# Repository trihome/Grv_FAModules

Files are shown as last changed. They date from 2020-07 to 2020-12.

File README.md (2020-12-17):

# FA Extension boards for Grove System

## 1.Introduction

This repository has an interface board for connecting equipment used in the factory to Seeed Studio's "Grove System".

<http://wiki.seeedstudio.com/Grove_System/>

These modules are used to make the equipment used in the factory (switches, sensors, relays, etc.) Allows you to connect to the GROVE system.

These boards support digital (GPIO), analog, and I2C connection types.

Refer to the READEME file in each directory for more information.

**Note**

Please import this library before using this repository.
<https://github.com/trihome/KiCad_MyLibrary>

**How to make**

[Manual (Japanese only)](https://github.com/trihome/RasPi_PiFA/blob/master/doc/README_pcb.jp.md)

## 2.Line up

|Module|Connection Type |function |
|:---|:---|:---|
|[IOExpander](./IOExpander16ch/) |I2C |Isolated input/output via I2C |
|[DigitalOutput](./DigitalOutput4ch)  |GPIO |Isolated output  |
|[DigitalInput](./DigitalInput4ch) |GPIO |Isolated input |
| | |(We will increase the lineup in the future...) |
<!--|CurrentSensor  |Analog  |Current measurement using CT  |
|SigTowSensor   |Analog  |Detect tower light status   |
|SimpleUPS      |GPIO    |Manage the power supply to RaspberryPi   |-->

## 3.How to connect to microcomputer board

If your board does not have a Grove connector, obtain a **Grove Expansion Board** to connect your Grove module.

- <http://wiki.seeedstudio.com/Platform/>

### (1)Arduino

- <http://wiki.seeedstudio.com/Base_Shield_V2/>

### (2)Raspberry Pi

- <http://wiki.seeedstudio.com/Grove_Base_Hat_for_Raspberry_Pi/>
- <http://wiki.seeedstudio.com/Grove_Base_Hat_for_Raspberry_Pi_Zero/>

### (3)micro:bit

- <https://www.seeedstudio.com/Grove-Shield-for-micro-bit-v2-0.html>

## 4.License

This is under [CC-BY-SA](https://creativecommons.org/licenses/by-sa/4.0/).

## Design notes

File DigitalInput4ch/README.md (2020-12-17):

# Digital Input 4ch

Digital Input for GROVE Digital.
Isolated inputs.

[Schematic](./img/DigitalInput4ch.pdf)

**Notes**

Please import this library before using this repository.
https://github.com/trihome/KiCad_MyLibrary

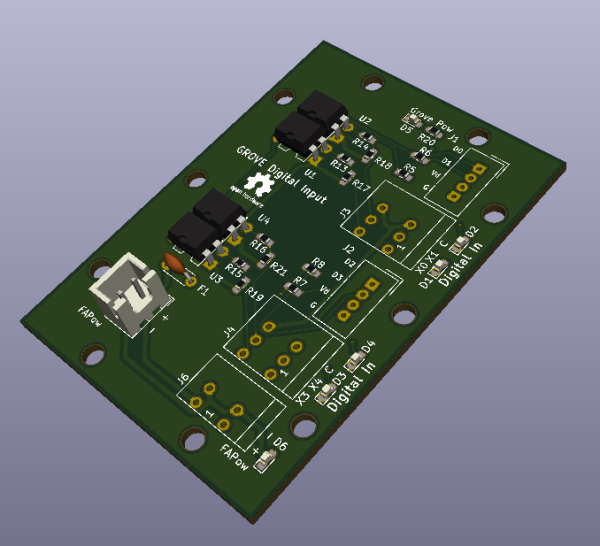
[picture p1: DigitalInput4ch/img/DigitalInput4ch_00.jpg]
di00 3D

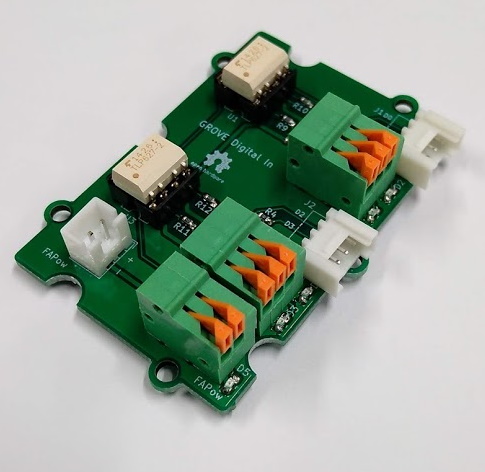
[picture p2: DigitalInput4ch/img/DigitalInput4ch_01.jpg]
di01 Usage


## 1.Spec

- 4 isolated inputs.
- [GROVE Digital](https://wiki.seeedstudio.com/Grove_System/#digital) Connector x 2 (2ch x 2 = 4ch)
- Supply 24V power to J5 or J6.
- J3,6 are Input for FA(24V)
  - Recommended Terminal block: [2pin](https://akizukidenshi.com/catalog/g/gP-06307/), [3pin](https://akizukidenshi.com/catalog/g/gP-06308/)
- Selectable Sink(NPN) / Source(PNP) : JP1, JP2
- U1,2,3,4: Photocoupler, you have to choose...

|JP1, JP2|Photocoupler (ex)|
|:--|:--|
|N : Sink(NPN)|[FOD814A300W](https://akizukidenshi.com/catalog/g/gI-06483/), [TLP627](https://akizukidenshi.com/catalog/g/gI-07691/)|
|P : Source(PNP)|[FOD814A300W](https://akizukidenshi.com/catalog/g/gI-06483/)|

## 2.Example of use

<!--
### (1)Terminal block

- Button
  - [IDEC](http://jp.idec.com/ja/p/c10/)
  - [OMRON](https://www.fa.omron.co.jp/products/category/switches/push-buttons_indicator-lamps/)
- Lamp
  - [NIKKEI MFG](http://www.nikkei-mfg.co.jp/product/industry/index.htm)
-->

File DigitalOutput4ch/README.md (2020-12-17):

# Digital Output 4ch

Digital Output for GROVE Digital.
Isolated outputs.

[Schematic](./img/DigitalOutput4ch.pdf)

**Notes**

Please import this library before using this repository.
https://github.com/trihome/KiCad_MyLibrary

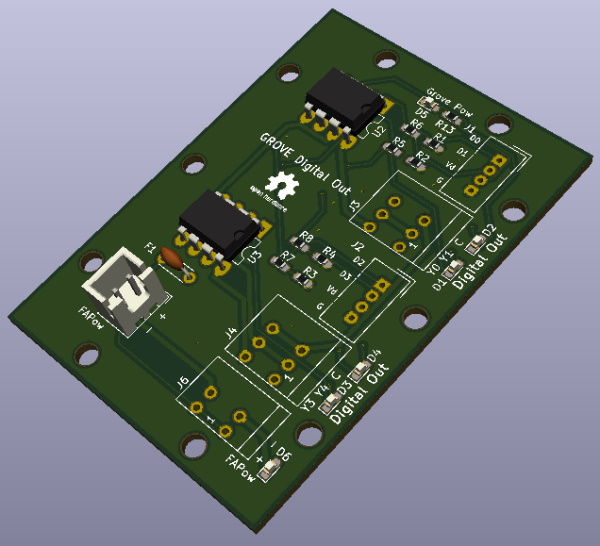
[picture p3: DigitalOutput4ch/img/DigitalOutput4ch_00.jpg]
do00 3D

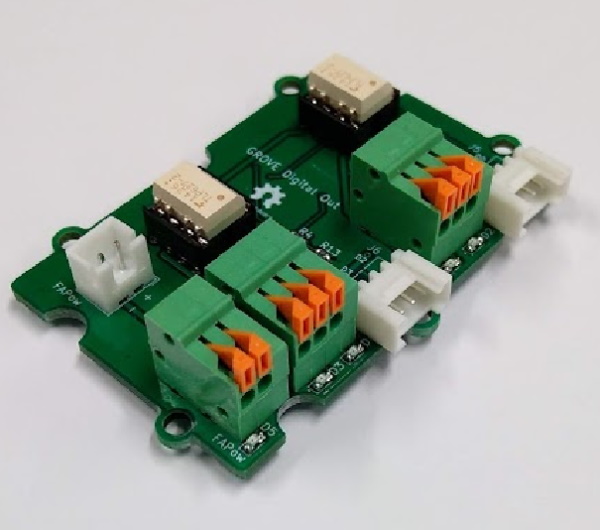
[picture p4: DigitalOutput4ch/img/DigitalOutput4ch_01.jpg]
do01 Usage


## 1.Spec

- 4 isolated outputs.
- [GROVE Digital](https://wiki.seeedstudio.com/Grove_System/#digital) Connector x 2 (2ch x 2 = 4ch)
- Supply 24V power to J5 or J6.
- J3,6 are Input for FA(24V)
  - Recommended Terminal block: [2pin](https://akizukidenshi.com/catalog/g/gP-06307/), [3pin](https://akizukidenshi.com/catalog/g/gP-06308/)
- Selectable Sink(NPN) / Source(PNP) : JP1, JP2
- U1,2,3,4: Photocoupler, you have to choose...

|JP1, JP2|Photocoupler (ex)|
|:--|:--|
|N : Sink(NPN)|[TLP222A](https://akizukidenshi.com/catalog/g/gI-07672/), [TLP627](https://akizukidenshi.com/catalog/g/gI-07691/)|
|P : Source(PNP)|[TLP222A](https://akizukidenshi.com/catalog/g/gI-07672/)|

## 2.Example of use

<!--
### (1)Terminal block

- Button
  - [IDEC](http://jp.idec.com/ja/p/c10/)
  - [OMRON](https://www.fa.omron.co.jp/products/category/switches/push-buttons_indicator-lamps/)
- Lamp
  - [NIKKEI MFG](http://www.nikkei-mfg.co.jp/product/industry/index.htm)
-->

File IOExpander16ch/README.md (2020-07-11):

# IO Expander 16ch

IO Expander for GROVE I2C.
Isolated inputs and outputs.

[Schematic](./img/IOExpander16ch.pdf)

**Notes**

Please import this library before using this repository.
https://github.com/trihome/KiCad_MyLibrary

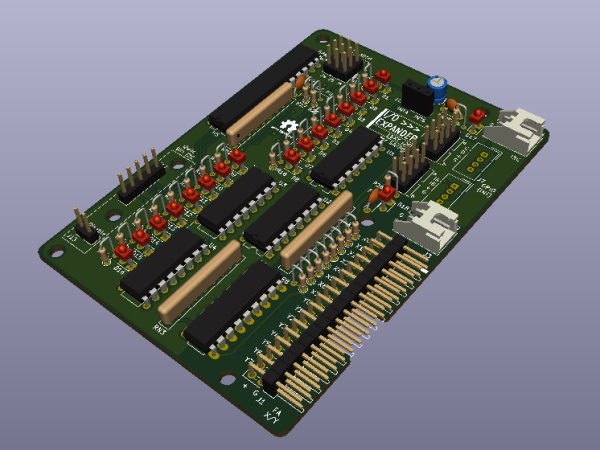
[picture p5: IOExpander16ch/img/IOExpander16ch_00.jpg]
ioexp1600 3D

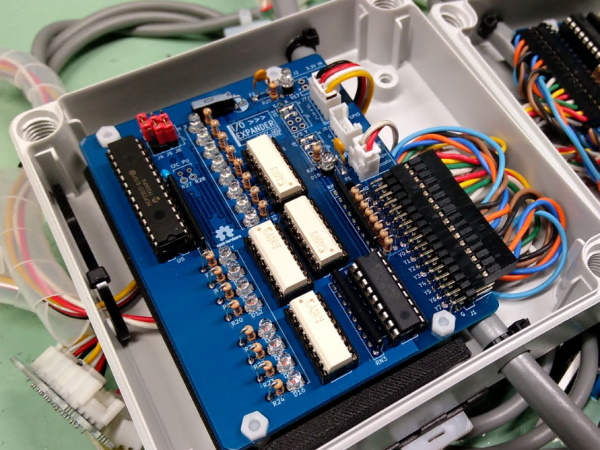
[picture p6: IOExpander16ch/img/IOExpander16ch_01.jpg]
ioexp1601 Usage


## 1.Spec

- 8 isolated inputs and 8 isolated outputs.
- I/O Expander : MCP23017
  - Select I2C address, J4,J5,J6.
  - I2C signal input to J7 (GROVE I2C).
  - INT A, B Pins are output to J8 (GROVE Digital).
- Supply 24V power to J3.
- J1 is Input / Output for FA(24V)
  - Recommended [Terminal block](https://www.togi.co.jp/product/interface/1072/) and [Cables](https://www.togi.co.jp/product/harness-cable/2661/) or QI(2550)connectors.
- Selectable Sink(NPN) / Source(PNP) : J9(Input), J10(Output)
  - IC1: Transistor array, you have to choose.
    - J10 = [Sink(NPN)](http://akizukidenshi.com/catalog/g/gI-10669/)
    - J10 = [Source(PNP)](http://akizukidenshi.com/catalog/g/gI-10957/)
- If you want to communicate with a distant location, add this board.
- [SparkFun Differential I2C Breakout - PCA9615](https://www.switch-science.com/catalog/3907/)

## 2.Example of use

### (1)Terminal block

- Terminal block (34 pin)
  - [Screw connection](https://www.togi.co.jp/product/interface/958/)
  - [Push-in connection(Ferrules)](https://www.togi.co.jp/product/interface/1086)
- [Cables](https://www.togi.co.jp/series/harness-cable/284/)
- Button
  - [IDEC](http://jp.idec.com/ja/p/c10/)
  - [OMRON](https://www.fa.omron.co.jp/products/category/switches/push-buttons_indicator-lamps/)
- Lamp
  - [NIKKEI MFG](http://www.nikkei-mfg.co.jp/product/industry/index.htm)

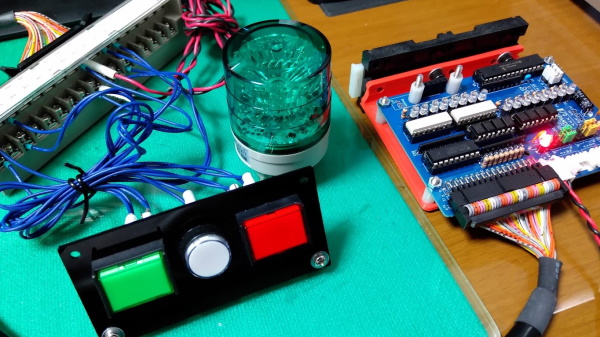
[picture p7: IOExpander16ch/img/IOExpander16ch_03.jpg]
ioexp1603 Usage

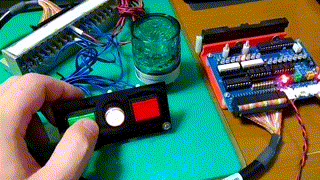
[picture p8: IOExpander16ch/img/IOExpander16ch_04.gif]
ioexp1604 Usage


### (2)Communicate with a device in a remote location

- [SparkFun Differential I2C Breakout - PCA9615](https://www.switch-science.com/catalog/3907/)
  - Connect to J12.
- Ethernet Cables (MAX 30 m)

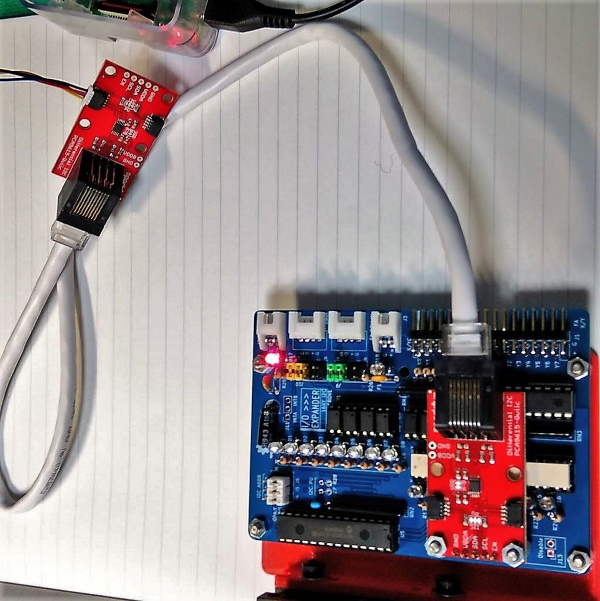
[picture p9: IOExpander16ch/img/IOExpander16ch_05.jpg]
ioexp1605 Usage

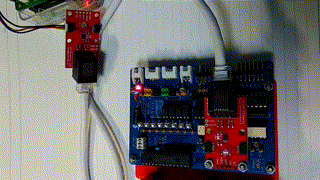
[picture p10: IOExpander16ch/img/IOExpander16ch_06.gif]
ioexp1606 Usage


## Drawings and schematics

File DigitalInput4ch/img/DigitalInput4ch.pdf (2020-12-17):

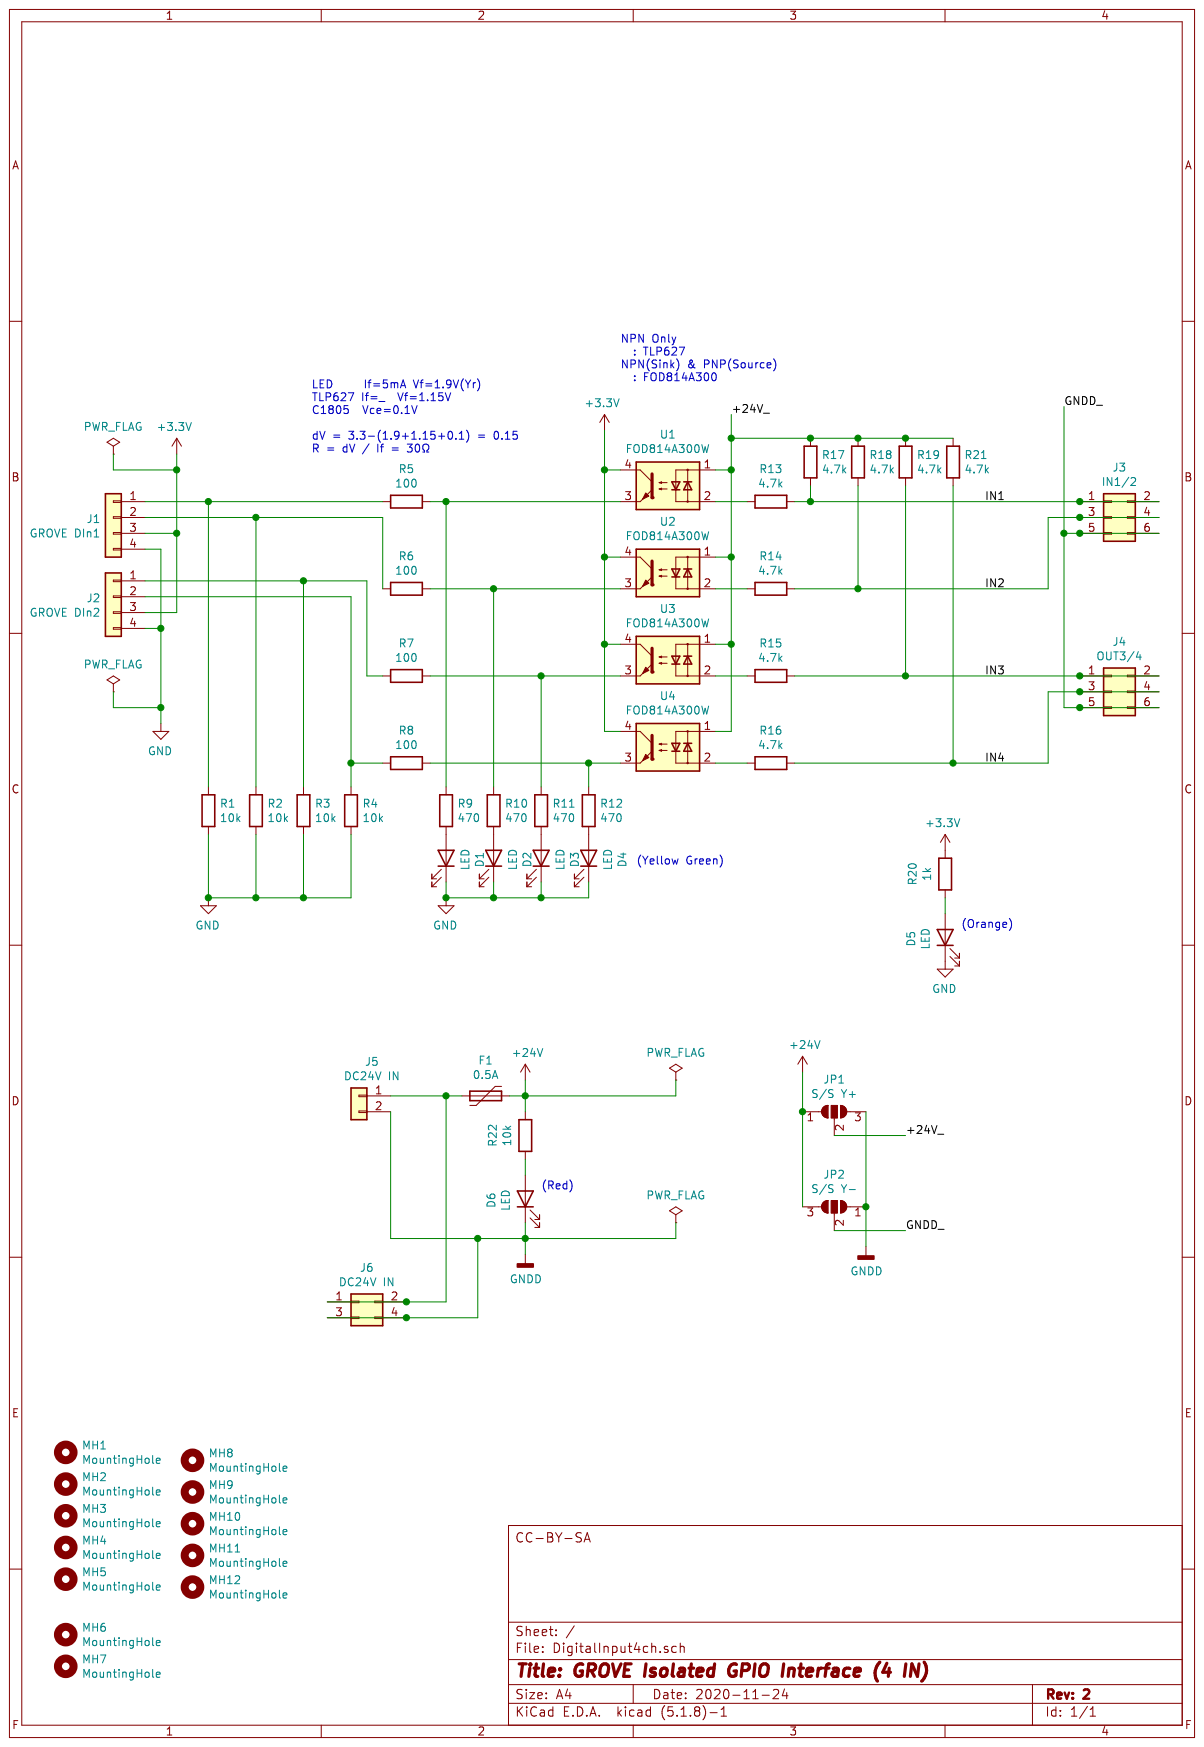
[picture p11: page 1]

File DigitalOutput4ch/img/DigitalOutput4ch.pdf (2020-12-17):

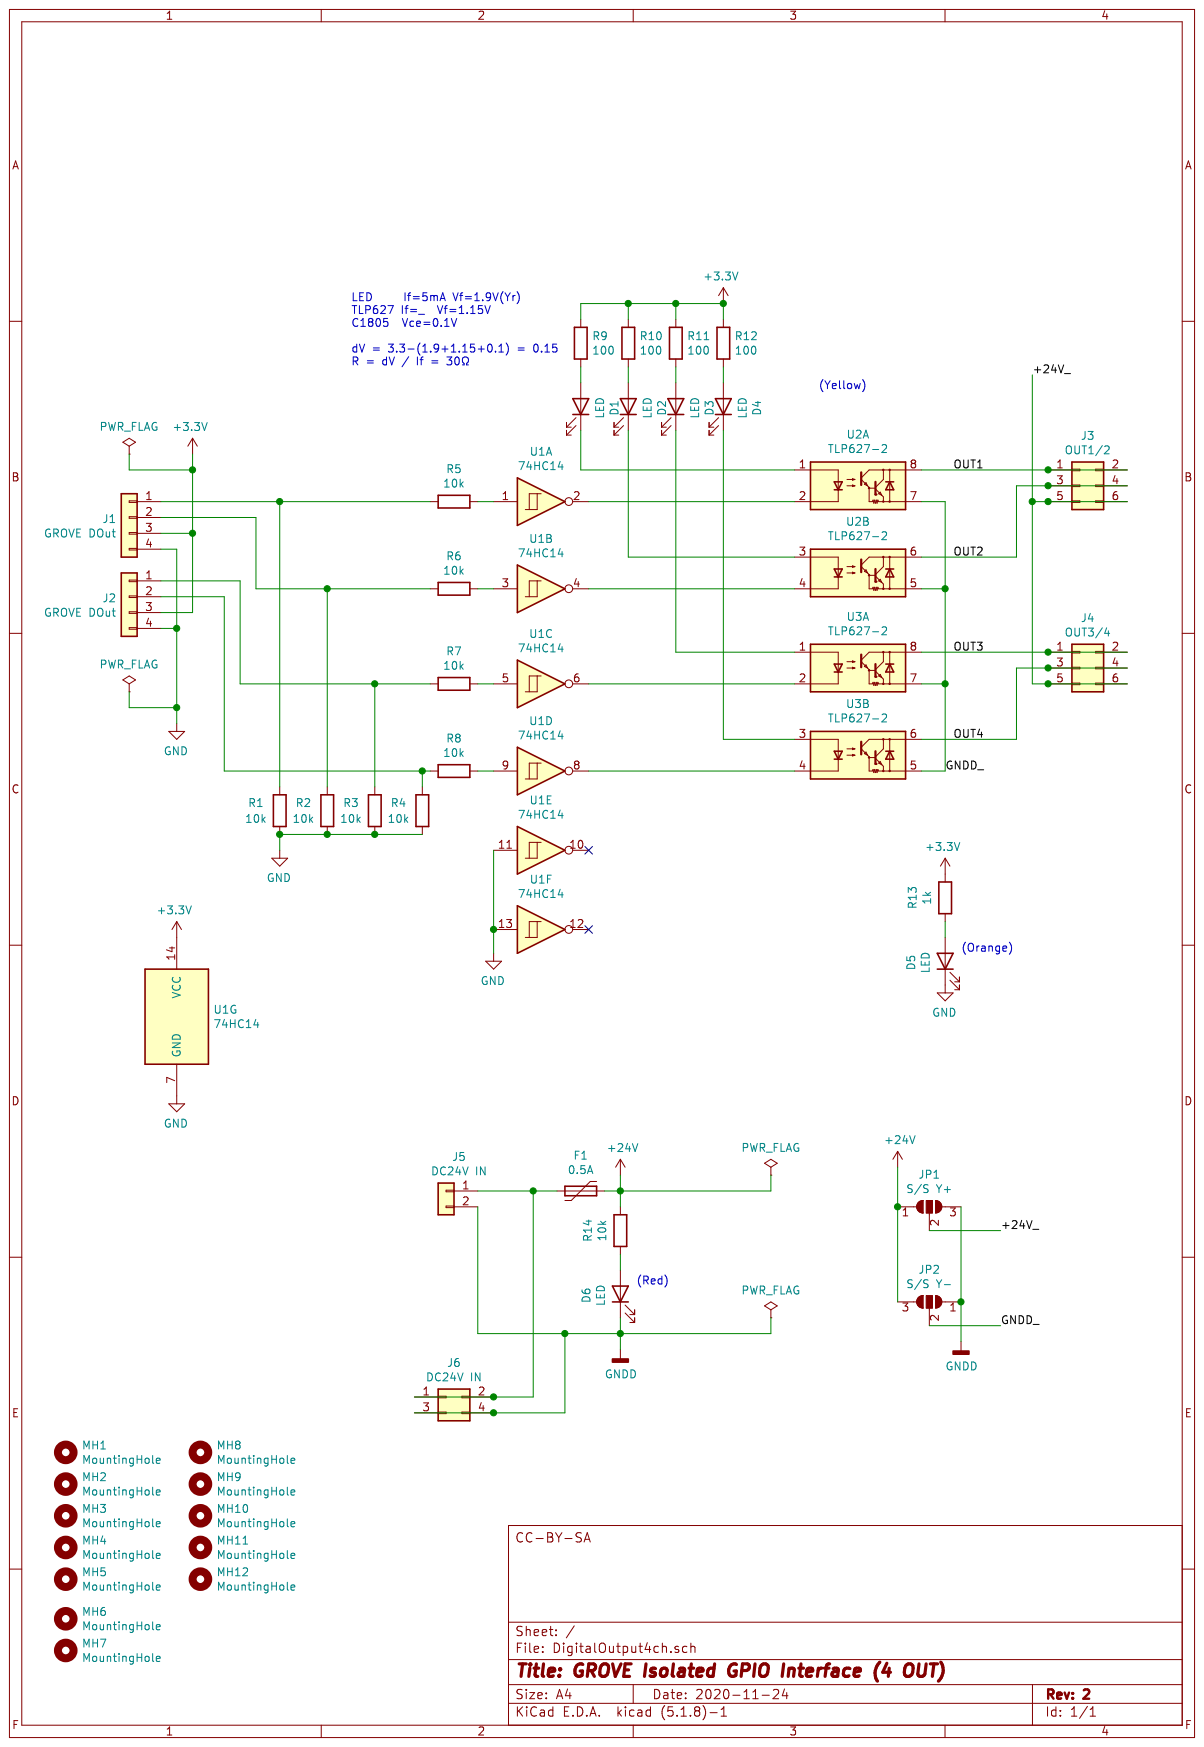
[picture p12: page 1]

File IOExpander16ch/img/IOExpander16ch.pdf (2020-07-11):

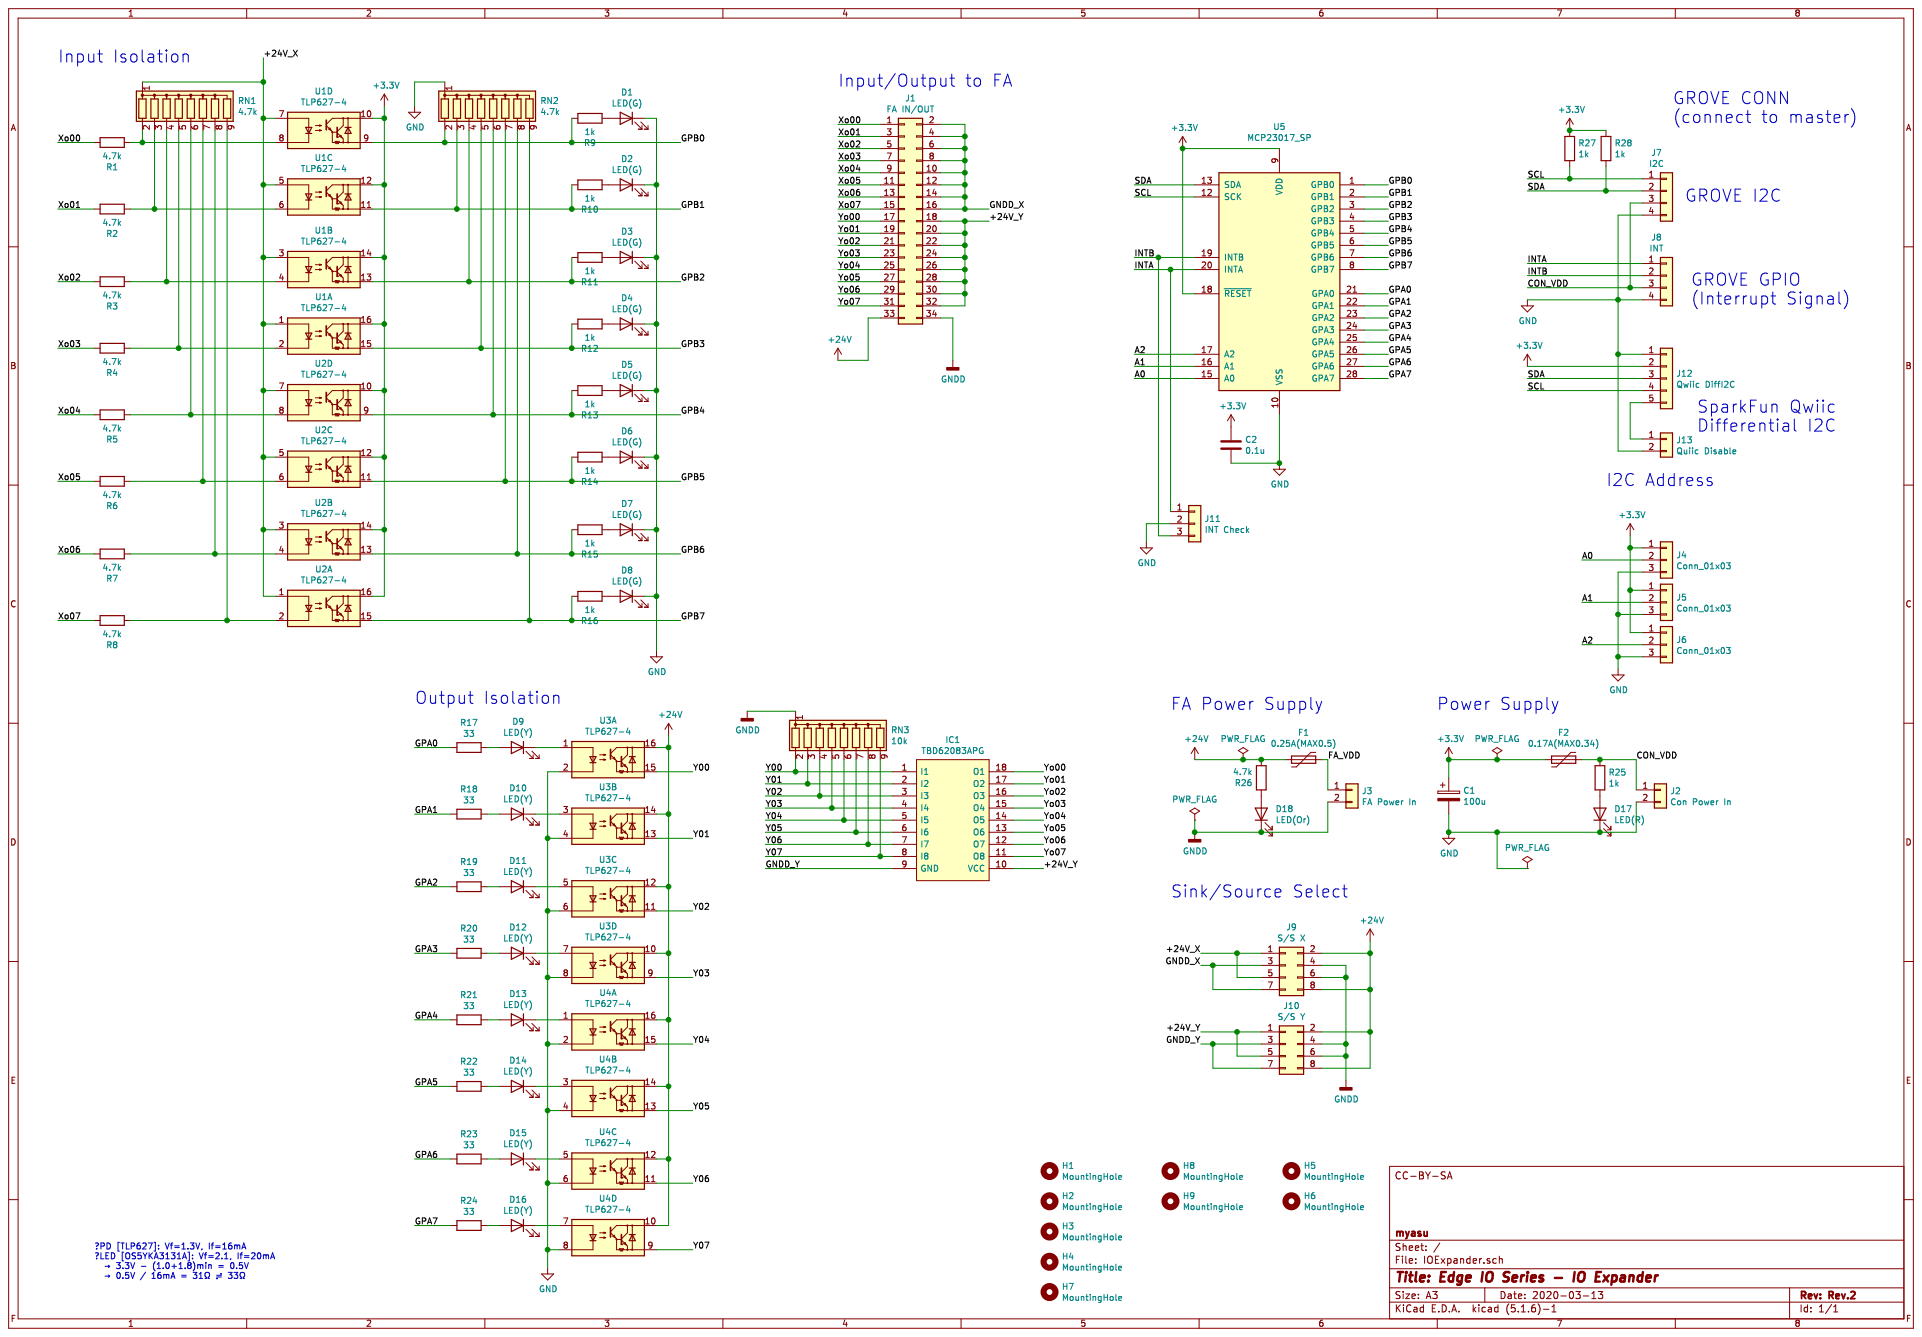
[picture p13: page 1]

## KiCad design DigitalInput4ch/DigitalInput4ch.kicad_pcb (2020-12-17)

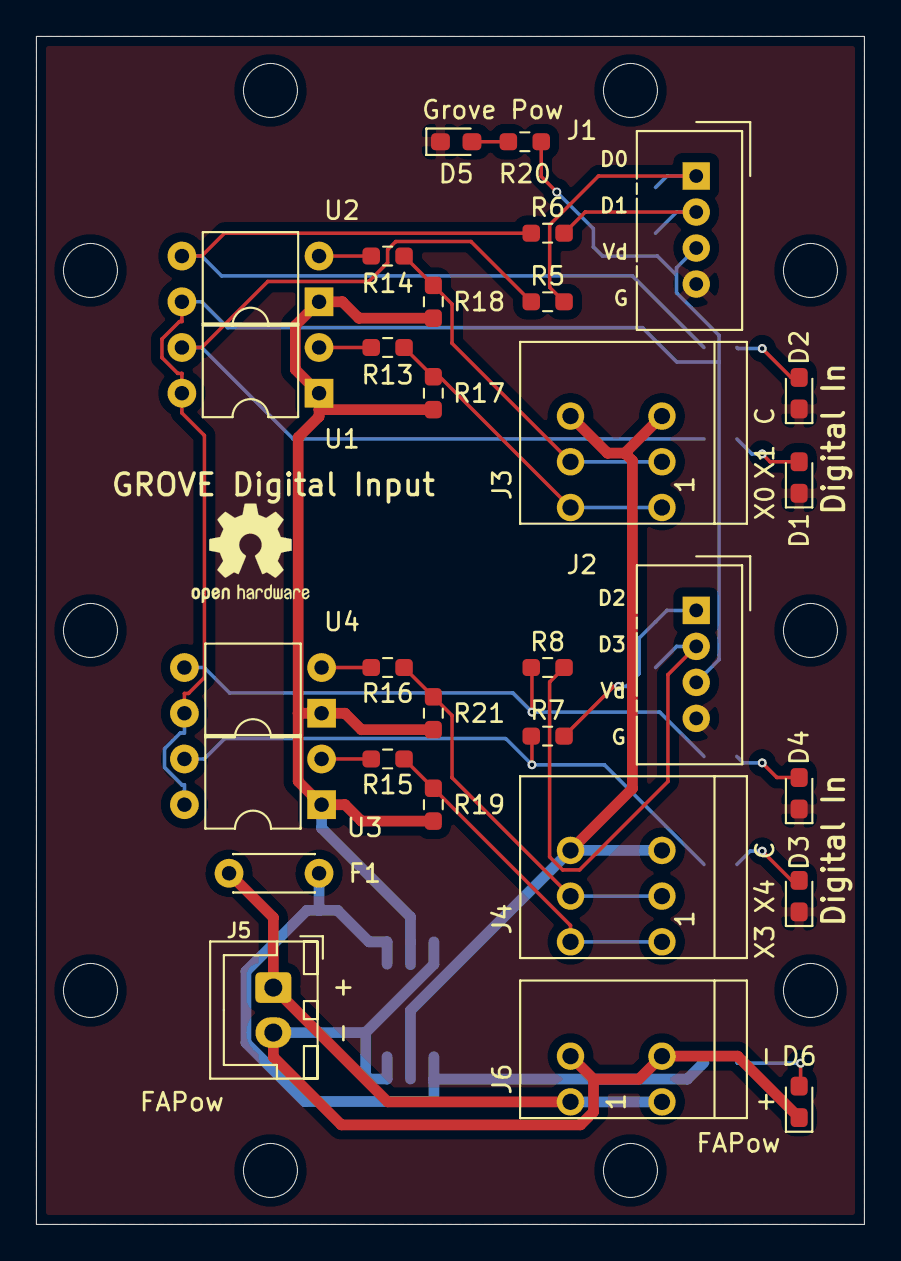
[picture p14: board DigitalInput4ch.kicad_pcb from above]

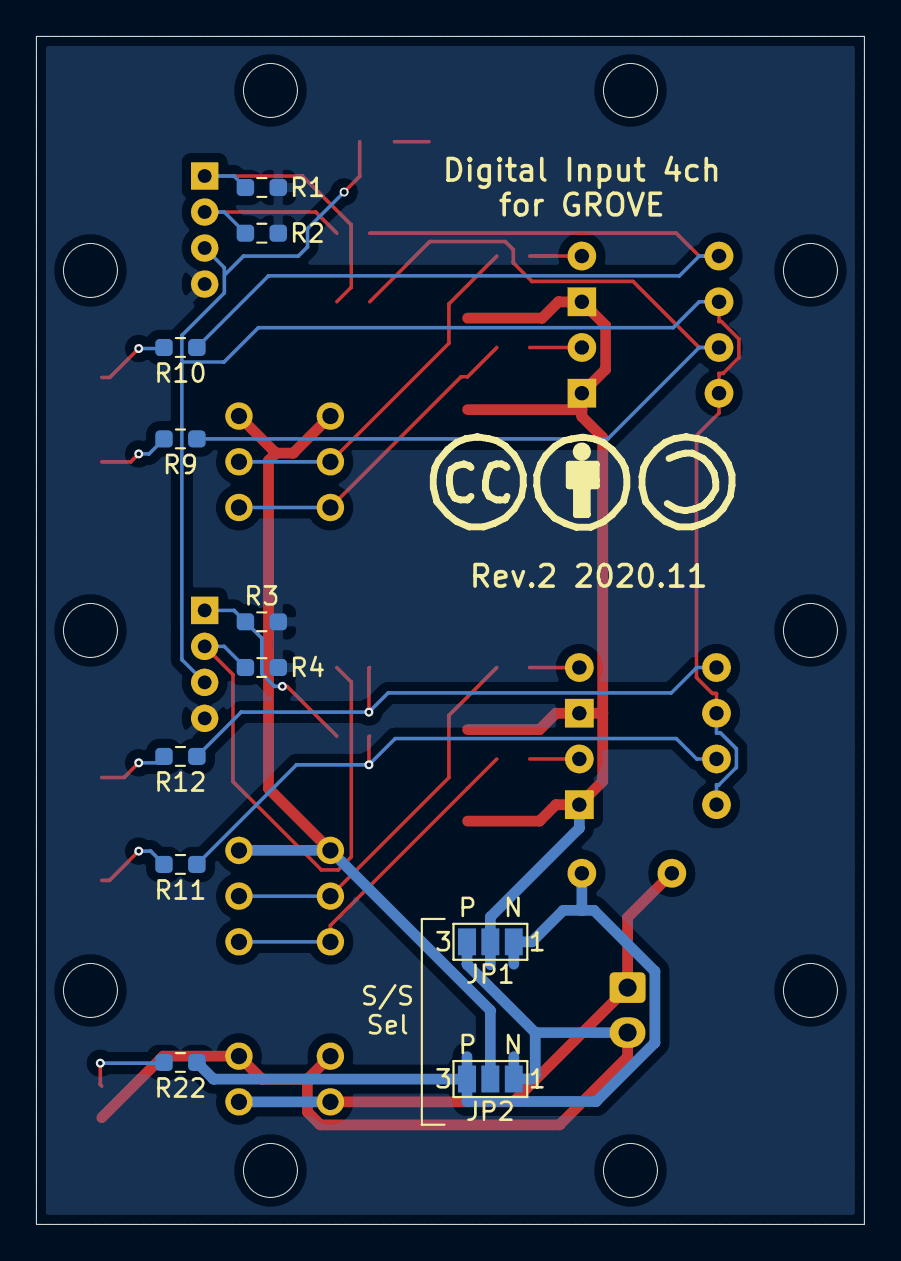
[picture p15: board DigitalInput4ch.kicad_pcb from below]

Board: 2 copper layers, 46.0 x 66.0 mm, 53 parts (11 on the bottom side), 29 nets.

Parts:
D1, D2, D3, D4, D5, D6: LED; LED_0603_1608Metric_Pad1.05x0.95mm_HandSolder
F1: 0.5A; C_Disc_D4.3mm_W1.9mm_P5.00mm
J1: GROVE DIn1; NS-Tech_Grove_1x04_P2mm_Vertical
J2: GROVE DIn2; NS-Tech_Grove_1x04_P2mm_Vertical
J3: IN1/2; Terminal_TB401a-1-3-E
J4: OUT3/4; Terminal_TB401a-1-3-E
J5: DC24V IN; JST_XH_B2B-XH-A_1x02_P2.50mm_Vertical
J6: DC24V IN; Terminal_TB401a-1-2-E
JP1: S/S Y+; SolderJumper-3_P1.3mm_Open_Pad1.0x1.5mm_NumberLabels
JP2: S/S Y-; SolderJumper-3_P1.3mm_Open_Pad1.0x1.5mm_NumberLabels
MH1, MH2, MH3, MH4, MH5, MH8, MH9, MH10, MH11, MH12: MountingHole; MountingHole_3mm
MH6: MountingHole; OSHW-Logo2_7.3x6mm_SilkScreen
MH7: MountingHole; CC-BY-SA
R1, R2, R3, R4, R22: 10k; R_0603_1608Metric_Pad0.98x0.95mm_HandSolder
R5, R6, R7, R8: 100; R_0603_1608Metric_Pad0.98x0.95mm_HandSolder
R9, R10, R11, R12: 470; R_0603_1608Metric_Pad0.98x0.95mm_HandSolder
R13, R14, R15, R16, R17, R18, R19, R21: 4.7k; R_0603_1608Metric_Pad0.98x0.95mm_HandSolder
R20: 1k; R_0603_1608Metric_Pad0.98x0.95mm_HandSolder
U1, U2, U3, U4: FOD814A300W; DIP-4_W7.62mm

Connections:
+3V3: J1.3, J2.3, R20.1, U1.4, U2.4, U3.4, U4.4
+24V: F1.1, JP1.1, JP2.3, R22.1
/+24V_: JP1.2, R17.1, R18.1, R19.1, R21.1, U1.1, U2.1, U3.1, U4.1
/GNDD_: J3.5, J3.6, J4.5, J4.6, JP2.2
/IN1: J3.1, J3.2, R13.1, R17.2
/IN2: J3.3, J3.4, R14.1, R18.2
/IN3: J4.1, J4.2, R15.1, R19.2
/IN4: J4.3, J4.4, R16.1, R21.2
GND: D1.1, D2.1, D3.1, D4.1, D5.1, J1.4, J2.4, R1.2, R2.2, R3.2, R4.2
GNDD: D6.1, J5.2, J6.3, J6.4, JP1.3, JP2.1
unnamed: D1.2, R9.2
unnamed: D2.2, R10.2
unnamed: D3.2, R11.2
unnamed: D4.2, R12.2
unnamed: D5.2, R20.2
unnamed: D6.2, R22.2
unnamed: F1.2, J5.1, J6.1, J6.2
unnamed: J1.1, R1.1, R5.2
unnamed: J1.2, R2.1, R6.2
unnamed: J2.1, R3.1, R7.2
unnamed: J2.2, R4.1, R8.2
unnamed: R5.1, R9.1, U1.3
unnamed: R6.1, R10.1, U2.3
unnamed: R7.1, R11.1, U3.3
unnamed: R8.1, R12.1, U4.3
unnamed: R13.2, U1.2
unnamed: R14.2, U2.2
unnamed: R15.2, U3.2
unnamed: R16.2, U4.2

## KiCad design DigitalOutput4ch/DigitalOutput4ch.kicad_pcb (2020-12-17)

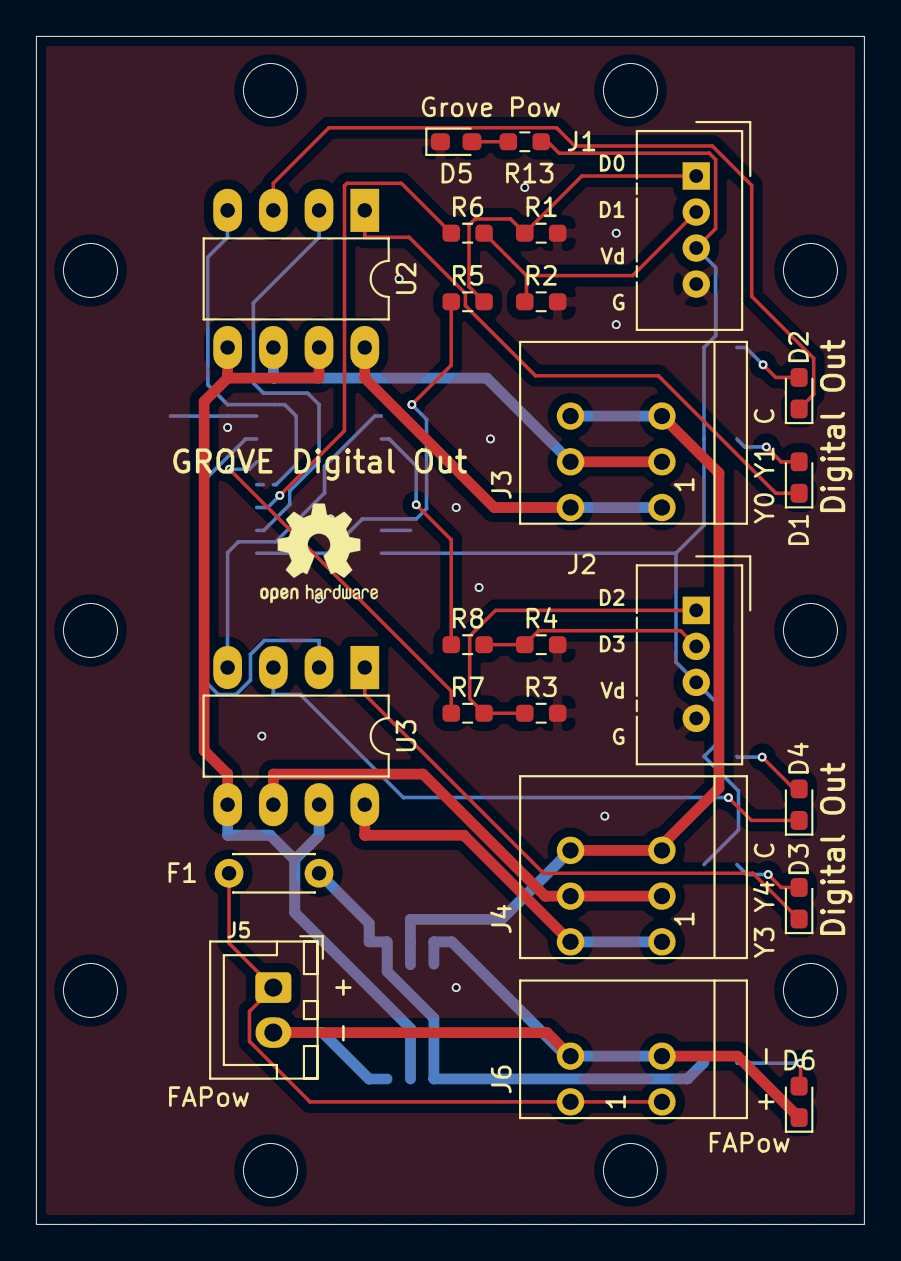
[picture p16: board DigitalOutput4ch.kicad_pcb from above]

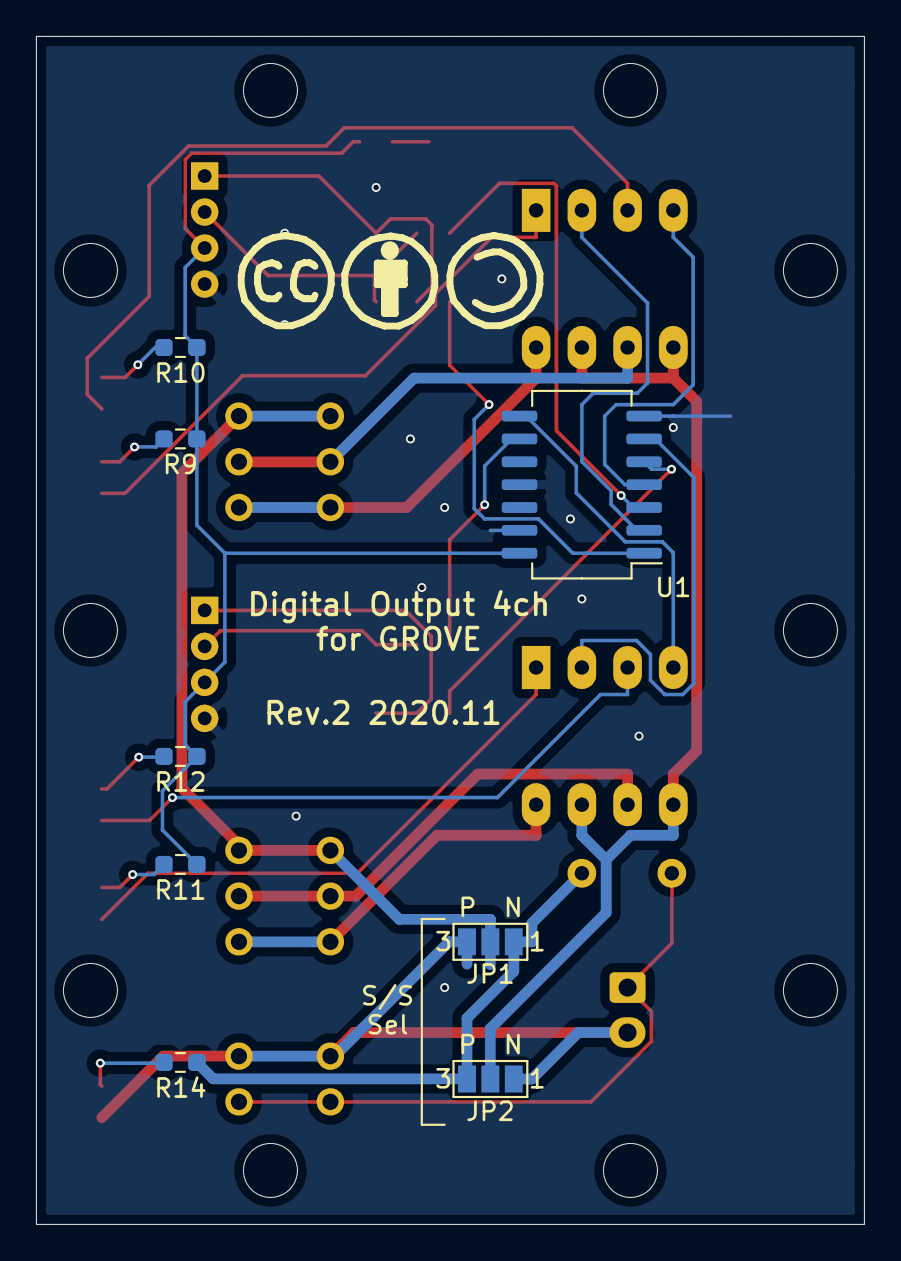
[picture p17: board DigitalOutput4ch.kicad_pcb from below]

Board: 2 copper layers, 46.0 x 66.0 mm, 44 parts (8 on the bottom side), 33 nets.

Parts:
D1, D2, D3, D4, D5, D6: LED; LED_0603_1608Metric_Pad1.05x0.95mm_HandSolder
F1: 0.5A; C_Disc_D4.3mm_W1.9mm_P5.00mm
J1, J2: GROVE DOut; NS-Tech_Grove_1x04_P2mm_Vertical
J3: OUT1/2; Terminal_TB401a-1-3-E
J4: OUT3/4; Terminal_TB401a-1-3-E
J5: DC24V IN; JST_XH_B2B-XH-A_1x02_P2.50mm_Vertical
J6: DC24V IN; Terminal_TB401a-1-2-E
JP1: S/S Y+; SolderJumper-3_P1.3mm_Open_Pad1.0x1.5mm_NumberLabels
JP2: S/S Y-; SolderJumper-3_P1.3mm_Open_Pad1.0x1.5mm_NumberLabels
MH1, MH2, MH3, MH4, MH5, MH8, MH9, MH10, MH11, MH12: MountingHole; MountingHole_3mm
MH6: MountingHole; OSHW-Logo2_7.3x6mm_SilkScreen
MH7: MountingHole; CC-BY-SA
R1, R2, R3, R4, R5, R6, R7, R8, R14: 10k; R_0603_1608Metric_Pad0.98x0.95mm_HandSolder
R9, R10, R11, R12: 100; R_0603_1608Metric_Pad0.98x0.95mm_HandSolder
R13: 1k; R_0603_1608Metric_Pad0.98x0.95mm_HandSolder
U1: 74HC14; SO-14_5.3x10.2mm_P1.27mm
U2, U3: TLP627-2; DIP-8_W7.62mm_LongPads

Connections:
+3V3: J1.3, J2.3, R9.1, R10.1, R11.1, R12.1, R13.1, U1.14
+24V: F1.1, JP1.1, JP2.3, R14.1
/+24V_: J3.5, J3.6, J4.5, J4.6, JP1.2
/GNDD_: JP2.2, U2.5, U2.7, U3.5, U3.7
/OUT1: J3.1, J3.2, U2.8
/OUT2: J3.3, J3.4, U2.6
/OUT3: J4.1, J4.2, U3.8
/OUT4: J4.3, J4.4, U3.6
GND: D5.1, J1.4, J2.4, R1.2, R2.2, R3.2, R4.2, U1.7, U1.11, U1.13
GNDD: D6.1, J5.2, J6.3, J6.4, JP1.3, JP2.1
unnamed: D1.1, U2.1
unnamed: D1.2, R9.2
unnamed: D2.1, U2.3
unnamed: D2.2, R10.2
unnamed: D3.1, U3.1
unnamed: D3.2, R11.2
unnamed: D4.1, U3.3
unnamed: D4.2, R12.2
unnamed: D5.2, R13.2
unnamed: D6.2, R14.2
unnamed: F1.2, J5.1, J6.1, J6.2
unnamed: J1.1, R1.1, R5.2
unnamed: J1.2, R2.1, R6.2
unnamed: J2.1, R3.1, R7.2
unnamed: J2.2, R4.1, R8.2
unnamed: R5.1, U1.1
unnamed: R6.1, U1.3
unnamed: R7.1, U1.5
unnamed: R8.1, U1.9
unnamed: U1.2, U2.2
unnamed: U1.4, U2.4
unnamed: U1.6, U3.2
unnamed: U1.8, U3.4

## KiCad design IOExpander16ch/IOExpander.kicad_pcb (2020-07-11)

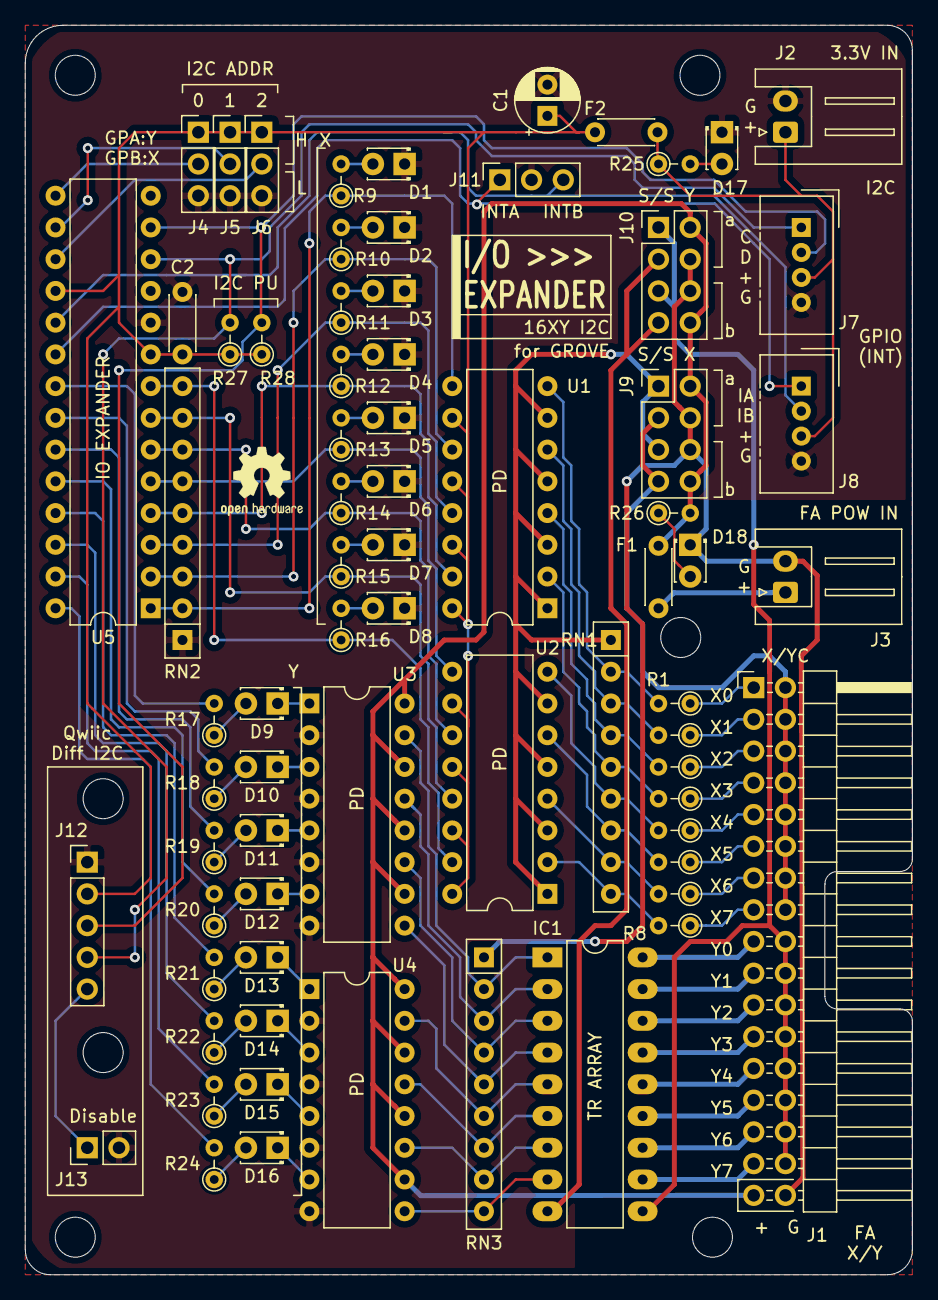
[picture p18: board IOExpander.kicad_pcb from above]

Board: 2 copper layers, 71.0 x 100.0 mm, 81 parts (0 on the bottom side), 92 nets.

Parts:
C1: 100u; CP_Radial_D5.0mm_P2.50mm
C2: 0.1u; C_Disc_D4.3mm_W1.9mm_P5.00mm
D1, D2, D3, D4, D5, D6, D7, D8: LED(G); LED_D1.8mm_W3.3mm_H2.4mm
D9, D10, D11, D12, D13, D14, D15, D16: LED(Y); LED_D1.8mm_W3.3mm_H2.4mm
D17: LED(R); LED_D1.8mm_W3.3mm_H2.4mm
D18: LED(Or); LED_D1.8mm_W3.3mm_H2.4mm
F1: 0.25A(MAX0.5); C_Disc_D4.3mm_W1.9mm_P5.00mm
F2: 0.17A(MAX0.34); C_Disc_D4.3mm_W1.9mm_P5.00mm
H1, H2, H3, H4, H7, H8, H9: MountingHole; MountingHole_3.2mm_M3
H5: MountingHole; OSHW-Logo2_7.3x6mm_SilkScreen
H6: MountingHole; CC-BY-SA
IC1: TBD62083APG; DIP-18_W7.62mm_LongPads
J1: FA IN/OUT; PinHeader_2x17_P2.54mm_Horizontal
J2: Con Power In; JST_XH_S2B-XH-A_1x02_P2.50mm_Horizontal
J3: FA Power In; JST_XH_S2B-XH-A_1x02_P2.50mm_Horizontal
J4, J5, J6: Conn_01x03; PinHeader_1x03_P2.54mm_Vertical
J7: I2C; NS-Tech_Grove_1x04_P2mm_Vertical
J8: INT; NS-Tech_Grove_1x04_P2mm_Vertical
J9: S/S X; PinHeader_2x04_P2.54mm_Vertical
J10: S/S Y; PinHeader_2x04_P2.54mm_Vertical
J11: INT Check; PinSocket_1x03_P2.54mm_Vertical
J12: Qwiic DiffI2C; PinHeader_1x05_P2.54mm_Vertical
J13: Quiic Disable; PinHeader_1x02_P2.54mm_Vertical
R1, R2, R3, R4, R5, R6, R7, R8, R26: 4.7k; R_Axial_DIN0204_L3.6mm_D1.6mm_P2.54mm_Vertical
R9, R10, R11, R12, R13, R14, R15, R16, R25, R27, R28: 1k; R_Axial_DIN0204_L3.6mm_D1.6mm_P2.54mm_Vertical
R17, R18, R19, R20, R21, R22, R23, R24: 33; R_Axial_DIN0204_L3.6mm_D1.6mm_P2.54mm_Vertical
RN1, RN2: 4.7k; R_Array_SIP9
RN3: 10k; R_Array_SIP9
U1, U2, U3, U4: TLP627-4; DIP-16_W7.62mm
U5: MCP23017_SP; DIP-28_W7.62mm

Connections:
+3V3: C1.1, C2.1, F2.2, J4.1, J5.1, J6.1, J12.2, R27.1, R28.1, U1.10, U1.12, U1.14, U1.16, U2.10, U2.12, U2.14, U2.16, U5.9, U5.18
+24V: F1.2, J1.33, J9.2, J9.8, J10.2, J10.8, R26.2, U3.10, U3.12, U3.14, U3.16, U4.10, U4.12, U4.14, U4.16
/+24V_X: J9.1, J9.5, RN1.1, U1.1, U1.3, U1.5, U1.7, U2.1, U2.3, U2.5, U2.7
/+24V_Y: IC1.10, J1.18, J1.20, J1.22, J1.24, J1.26, J1.28, J1.30, J1.32, J10.1, J10.5
/A0: J4.2, U5.15
/A1: J5.2, U5.16
/A2: J6.2, U5.17
/CON_VDD: F2.1, J2.1, J7.3, J8.3, R25.1
/FA_VDD: F1.1, J3.1
/GNDD_X: J1.2, J1.4, J1.6, J1.8, J1.10, J1.12, J1.14, J1.16, J9.3, J9.7
/GNDD_Y: IC1.9, J10.3, J10.7
/GPA0: R17.2, U5.21
/GPA1: R18.2, U5.22
/GPA2: R19.2, U5.23
/GPA3: R20.2, U5.24
/GPA4: R21.2, U5.25
/GPA5: R22.2, U5.26
/GPA6: R23.2, U5.27
/GPA7: R24.2, U5.28
/GPB0: R9.1, RN2.2, U1.9, U5.1
/GPB1: R10.1, RN2.3, U1.11, U5.2
/GPB2: R11.1, RN2.4, U1.13, U5.3
/GPB3: R12.1, RN2.5, U1.15, U5.4
/GPB4: R13.1, RN2.6, U2.9, U5.5
/GPB5: R14.1, RN2.7, U2.11, U5.6
/GPB6: R15.1, RN2.8, U2.13, U5.7
/GPB7: R16.1, RN2.9, U2.15, U5.8
/INTA: J8.1, J11.1, U5.20
/INTB: J8.2, J11.3, U5.19
/SCL: J7.1, J12.4, R27.2, U5.12
/SDA: J7.2, J12.3, R28.2, U5.13
/Xo00: J1.1, R1.1
/Xo01: J1.3, R2.1
/Xo02: J1.5, R3.1
/Xo03: J1.7, R4.1
/Xo04: J1.9, R5.1
/Xo05: J1.11, R6.1
/Xo06: J1.13, R7.1
/Xo07: J1.15, R8.1
/Y00: IC1.1, RN3.2, U3.15
/Y01: IC1.2, RN3.3, U3.13
/Y02: IC1.3, RN3.4, U3.11
/Y03: IC1.4, RN3.5, U3.9
/Y04: IC1.5, RN3.6, U4.15
/Y05: IC1.6, RN3.7, U4.13
/Y06: IC1.7, RN3.8, U4.11
/Y07: IC1.8, RN3.9, U4.9
/Yo00: IC1.18, J1.17
/Yo01: IC1.17, J1.19
/Yo02: IC1.16, J1.21
/Yo03: IC1.15, J1.23
/Yo04: IC1.14, J1.25
/Yo05: IC1.13, J1.27
/Yo06: IC1.12, J1.29
/Yo07: IC1.11, J1.31
GND: C1.2, C2.2, D1.1, D2.1, D3.1, D4.1, D5.1, D6.1, D7.1, D8.1, D17.1, J2.2, J4.3, J5.3, J6.3, J7.4, J8.4, J11.2, J12.1, J13.2, RN2.1, U3.2, U3.4, U3.6, U3.8, U4.2, U4.4, U4.6, U4.8, U5.10
GNDD: D18.1, J1.34, J3.2, J9.4, J9.6, J10.4, J10.6, RN3.1
unnamed: D1.2, R9.2
unnamed: D2.2, R10.2
unnamed: D3.2, R11.2
unnamed: D4.2, R12.2
unnamed: D5.2, R13.2
unnamed: D6.2, R14.2
unnamed: D7.2, R15.2
unnamed: D8.2, R16.2
unnamed: D9.1, U3.1
unnamed: D9.2, R17.1
unnamed: D10.1, U3.3
unnamed: D10.2, R18.1
unnamed: D11.1, U3.5
unnamed: D11.2, R19.1
unnamed: D12.1, U3.7
unnamed: D12.2, R20.1
unnamed: D13.1, U4.1
unnamed: D13.2, R21.1
unnamed: D14.1, U4.3
unnamed: D14.2, R22.1
unnamed: D15.1, U4.5
unnamed: D15.2, R23.1
unnamed: D16.1, U4.7
unnamed: D16.2, R24.1
unnamed: D17.2, R25.2
unnamed: D18.2, R26.1
unnamed: J12.5, J13.1
unnamed: R1.2, RN1.2, U1.8
unnamed: R2.2, RN1.3, U1.6
unnamed: R3.2, RN1.4, U1.4
unnamed: R4.2, RN1.5, U1.2
unnamed: R5.2, RN1.6, U2.8
unnamed: R6.2, RN1.7, U2.6
unnamed: R7.2, RN1.8, U2.4
unnamed: R8.2, RN1.9, U2.2

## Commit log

2020-07-11 Add files.(IO Expander 16ch)
    [IOExpander.GBL, IOExpander.GBO, IOExpander.GBP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]
2020-12-17 Add files. (Digital Input 4ch, Output 4ch)
    [DigitalInput4ch.kicad_pcb, DigitalInput4ch.sch, DigitalOutput4ch.kicad_pcb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]
2020-12-17 Fix typo in docs.
    [DigitalInput4chS.GBL, DigitalInput4chS.GBO, DigitalInput4chS.GBP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]

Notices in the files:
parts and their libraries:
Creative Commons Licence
